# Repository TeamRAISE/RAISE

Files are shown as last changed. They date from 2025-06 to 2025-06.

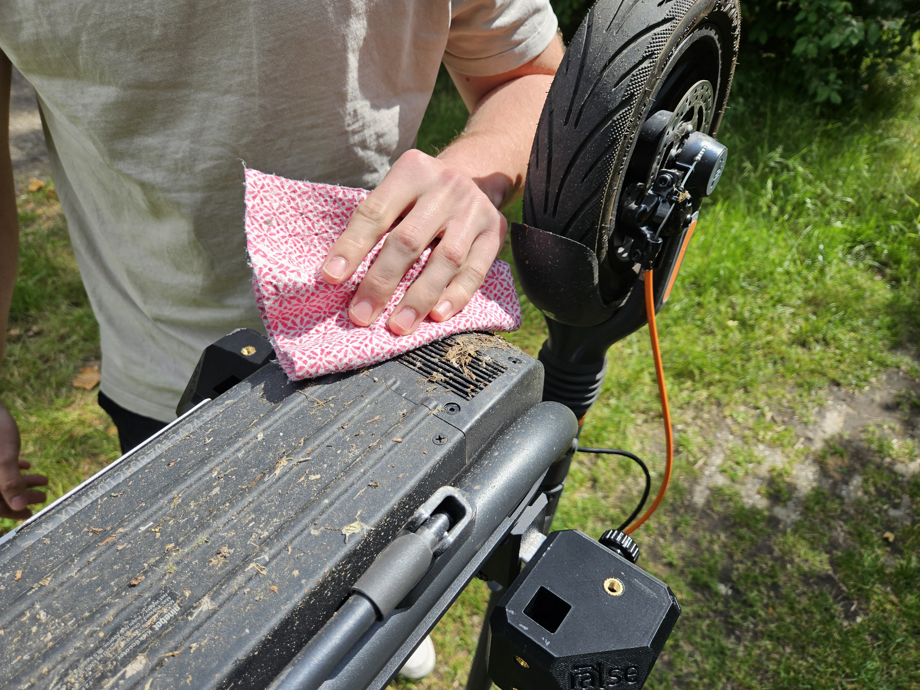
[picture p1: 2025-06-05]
Pictures/Wartungsgestell_Bild_03.jpg

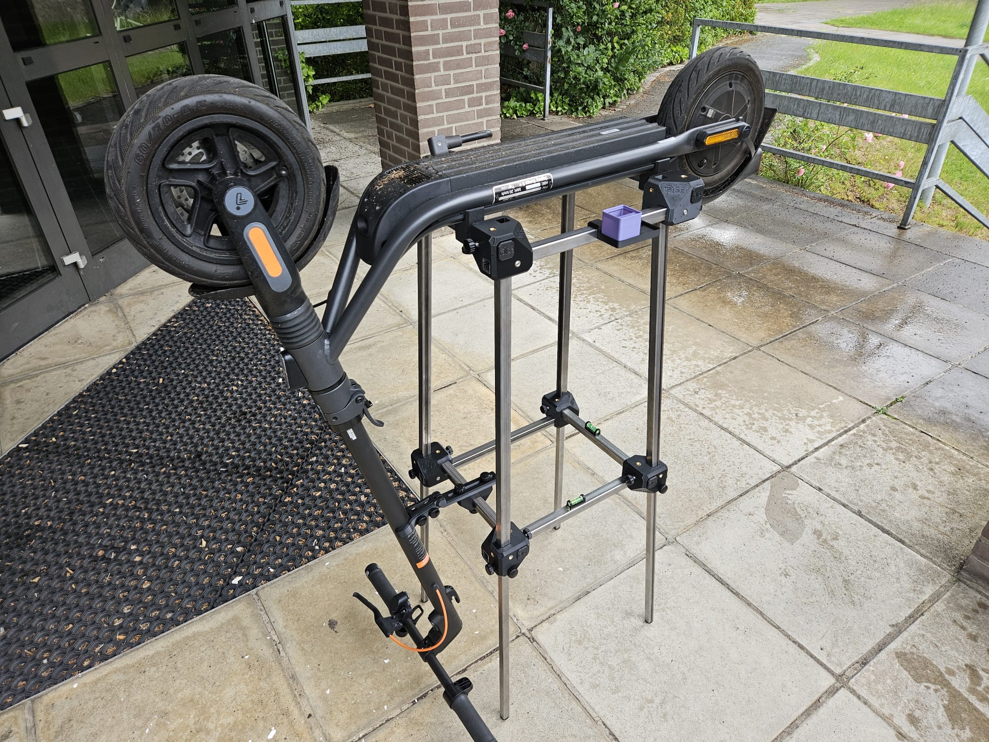
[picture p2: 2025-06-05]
Pictures/Wartungsgestell_Bild_05.jpeg

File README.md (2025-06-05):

# RAISE
Repair and Inspection Stand for E-Scooter

RAISE ist ein Wartungsgestell für E-Scooter. Wenn man einen E-Scooter besitzt, ist man für die Wartung,
Instandhaltung und das Reinigen des Rollers verantwortlich. Die Form des Rollers ist für eine Wartung
und Reinigung an der Unterseite ungünstig. Aufgrund der hohen Lenksäule und dem Hinterradspritzschutz
ist ein einfaches Ablegen auf einer herkömmlichen Tischplatte nicht möglich. Mit diesem an die Abmaße
eines E-Scooters angepassten Wartungsgestell ist es möglich, die Unterseite des Rollers auf eine angenehme
Arbeitshöhe zu bringen. Die zum Nachbau des Gestells benötigten Teile sind hier auf GitHub hinterlegt.
Es lässt sich mit einem 3D-Drucker und einfachen Mitteln aus dem Baumarkt nachbauen.

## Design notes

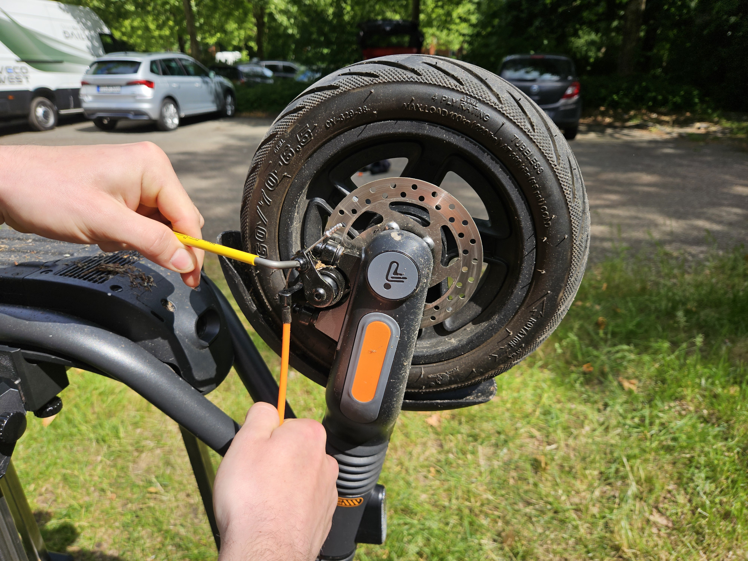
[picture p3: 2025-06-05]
Pictures/Wartungsgestell_Bild_02.jpg

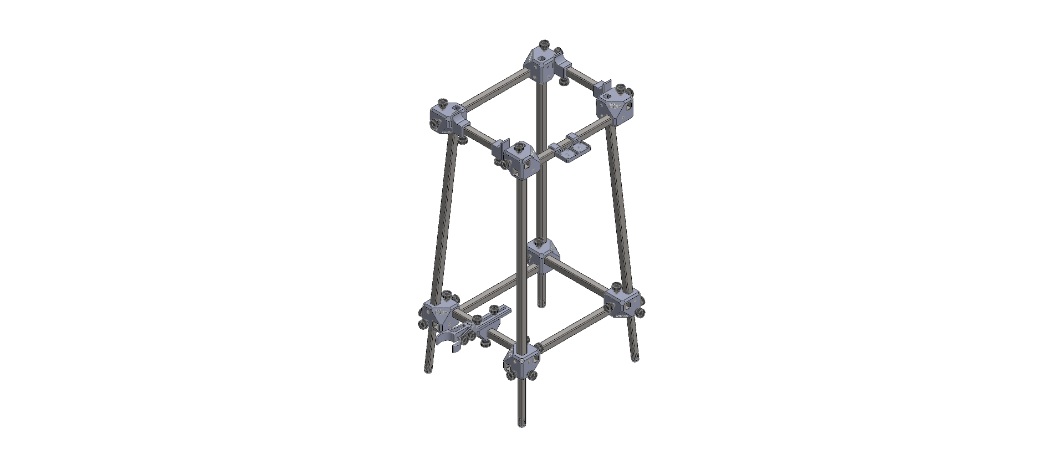
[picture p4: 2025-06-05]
Pictures/Wartungsgestell_Bild_01.PNG

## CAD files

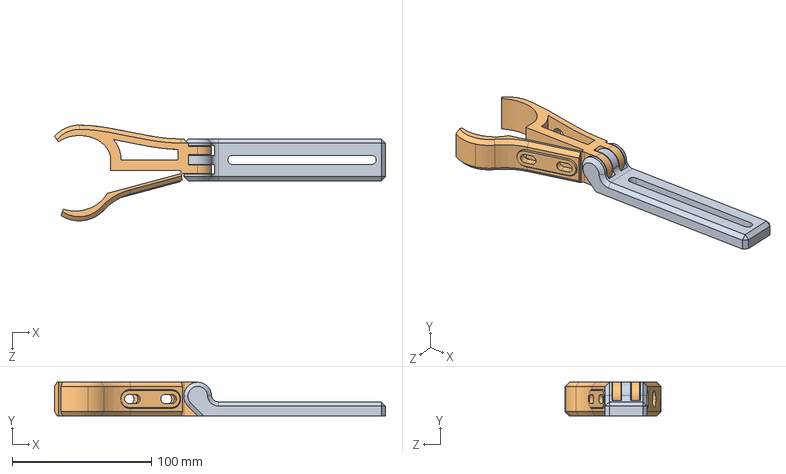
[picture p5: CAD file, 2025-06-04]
CAD/Säulenhalterung_Klemme_o.STEP
237.9 x 24.1 x 68.8 mm

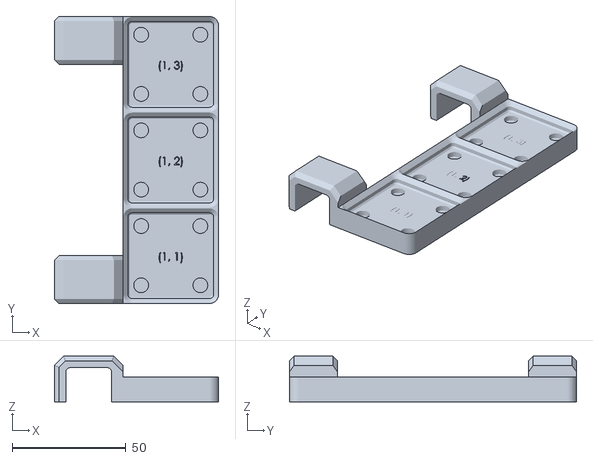
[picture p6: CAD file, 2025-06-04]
STL/Gridfinity/Baseplate_1-3.STL
72.1 x 126.0 x 20.0

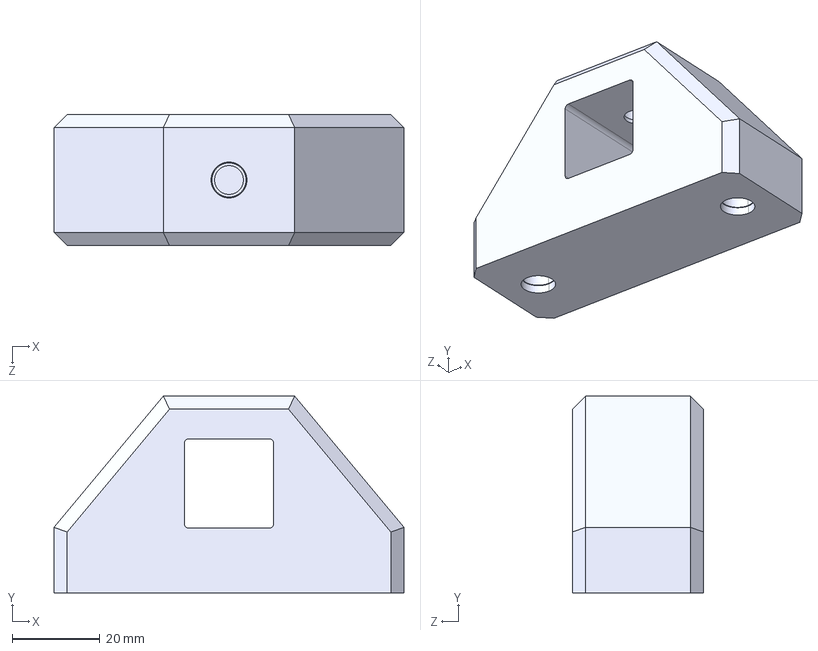
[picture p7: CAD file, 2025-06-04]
CAD/Säulenhalterung_Brücke_o.STEP
80.0 x 45.0 x 30.0 mm

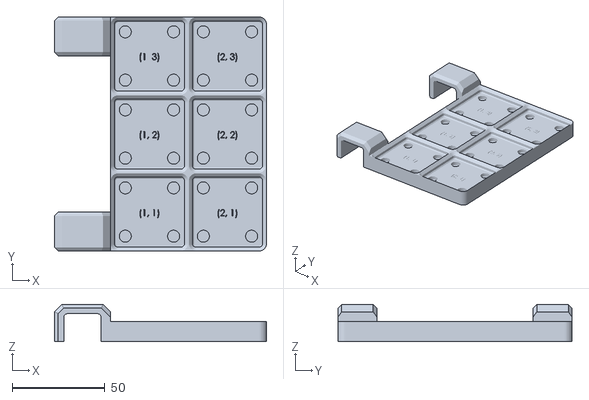
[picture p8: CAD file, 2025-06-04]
STL/Gridfinity/Baseplate_2-3.STL
114.1 x 126.0 x 20.0

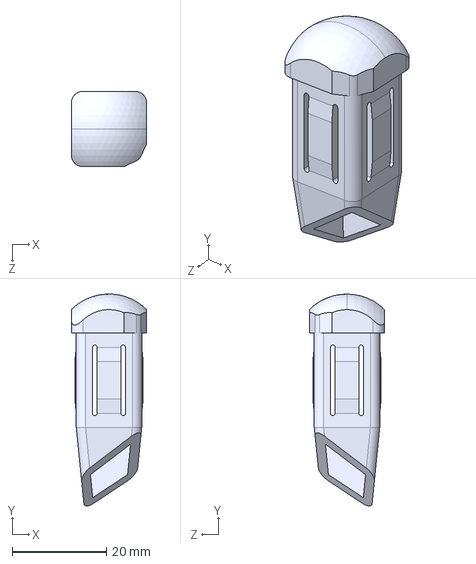
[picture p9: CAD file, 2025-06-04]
CAD/Endkappe_Fuß_x4.STEP
16.0 x 45.0 x 16.0 mm

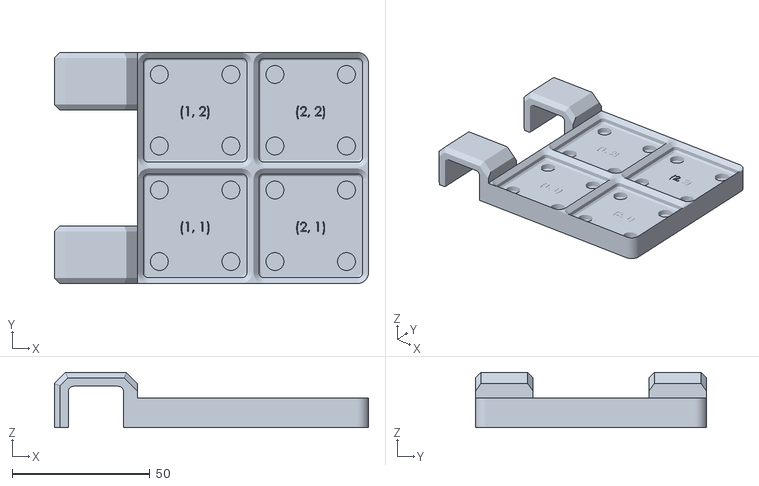
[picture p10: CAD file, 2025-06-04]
STL/Gridfinity/Baseplate_2-2.STL
114.1 x 84.0 x 20.0

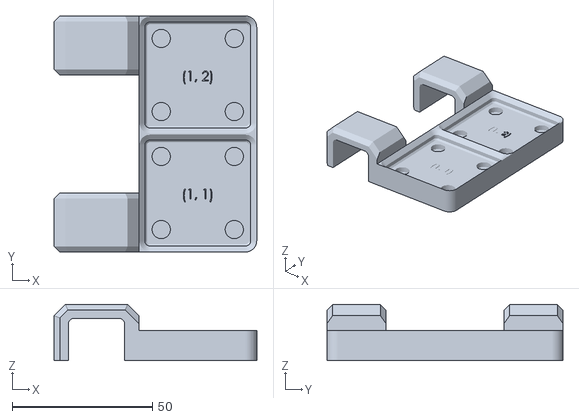
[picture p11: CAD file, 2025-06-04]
STL/Gridfinity/Baseplate_1-2.STL
72.1 x 84.0 x 20.0

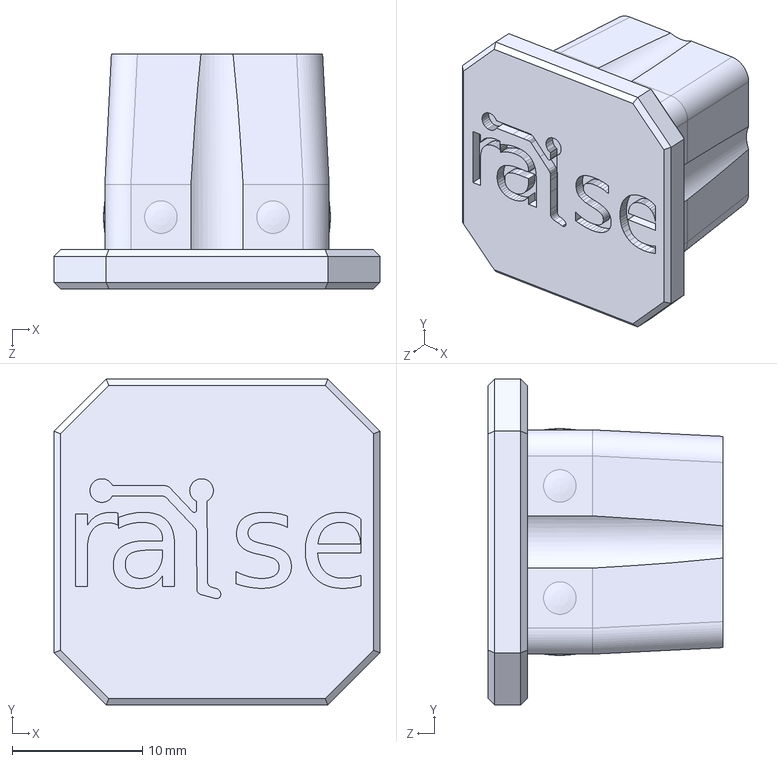
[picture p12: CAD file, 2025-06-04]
CAD/Endkappe_Logo_x16.STEP
25.0 x 25.0 x 18.0 mm

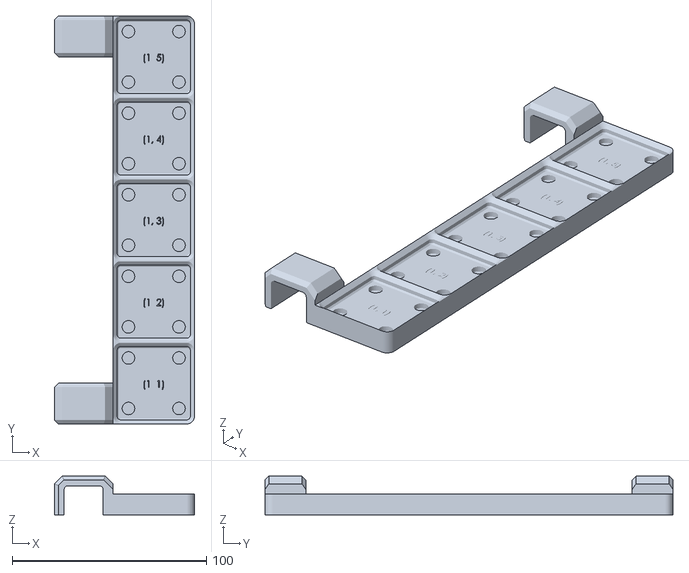
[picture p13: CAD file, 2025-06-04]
STL/Gridfinity/Baseplate_1-5.STL
72.1 x 210.0 x 20.0

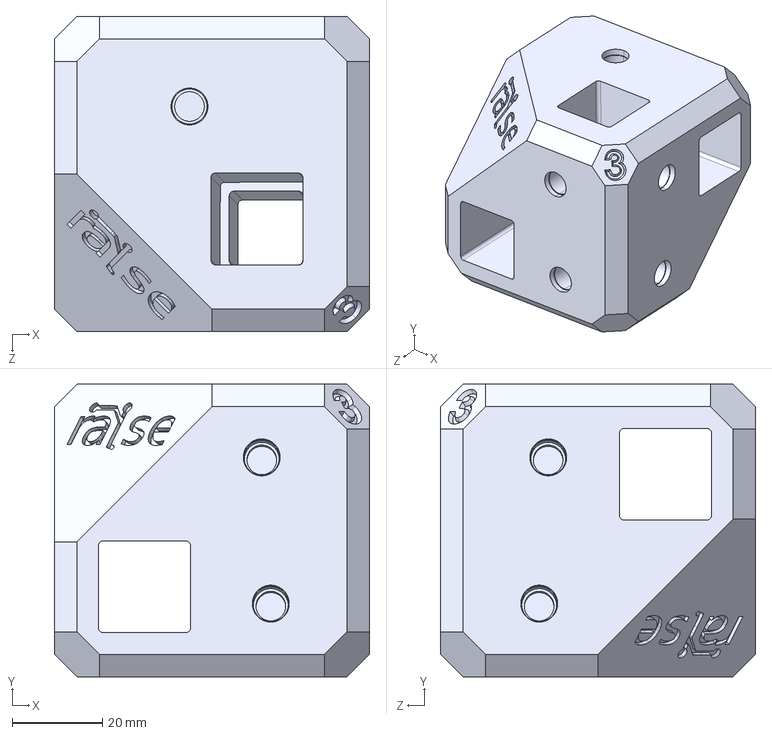
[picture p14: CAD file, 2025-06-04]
CAD/Eckwürfel_links_x4.STEP
70.0 x 65.0 x 70.0 mm

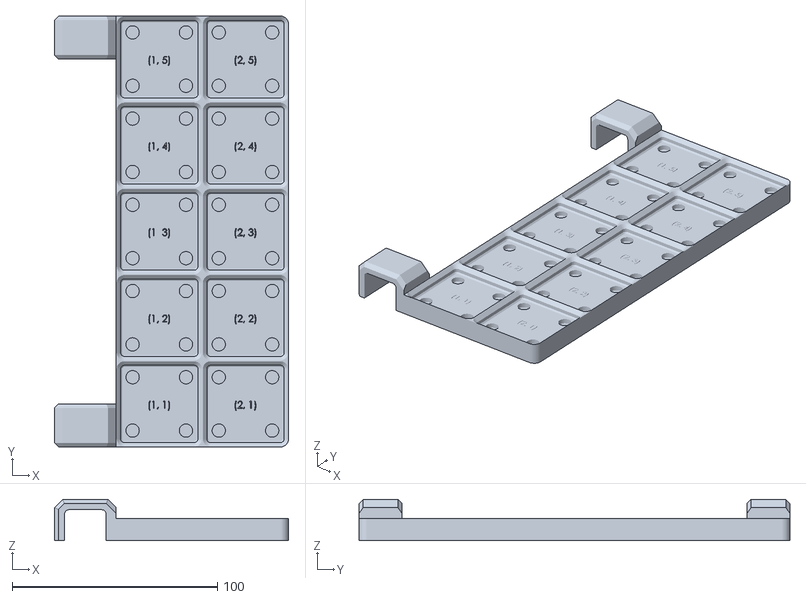
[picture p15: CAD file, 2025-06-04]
STL/Gridfinity/Baseplate_2-5.STL
114.1 x 210.0 x 20.0

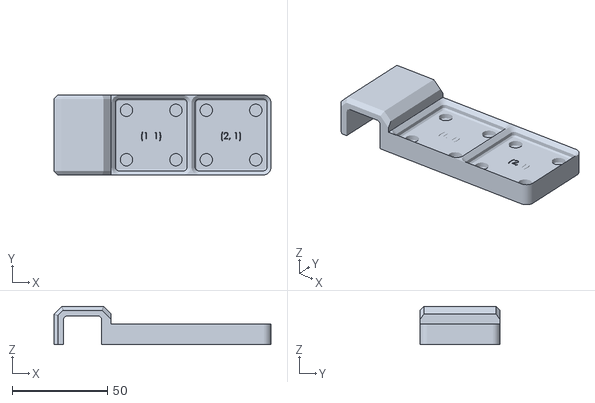
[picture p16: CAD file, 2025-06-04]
STL/Gridfinity/Baseplate_2-1.STL
114.1 x 42.0 x 20.0

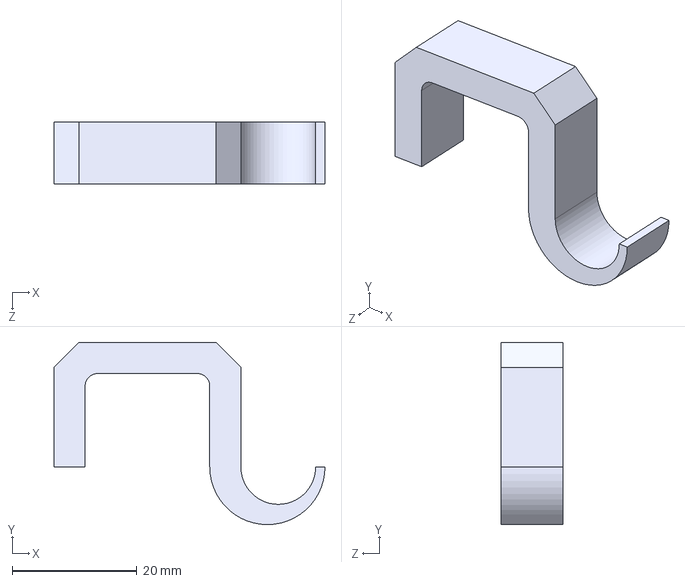
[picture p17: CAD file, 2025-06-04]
CAD/Haken_o.STEP
43.5 x 29.2 x 10.0 mm

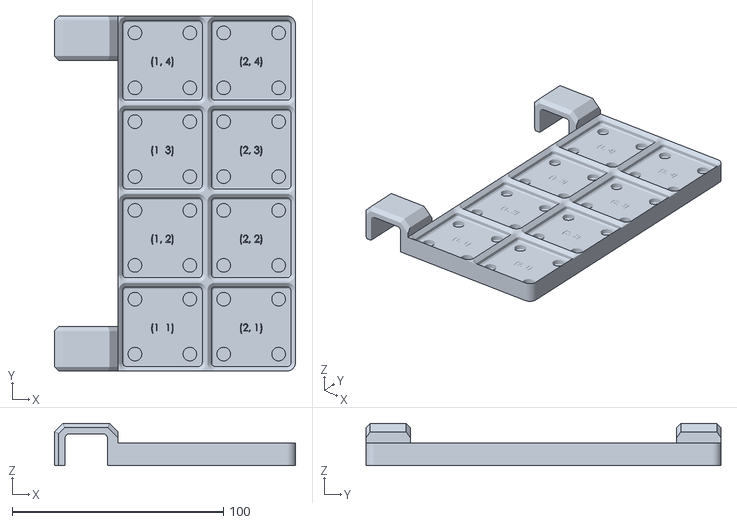
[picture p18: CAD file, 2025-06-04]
STL/Gridfinity/Baseplate_2-4.STL
114.1 x 168.0 x 20.0

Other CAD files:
CAD/Säulenhalterung_Brücke_01.STEP
CAD/Eckwürfel_rechts_x4.STEP
CAD/Endkappe_Fuß_01.STEP
STL/Gridfinity/Baseplate_1-4.STL
CAD/Scooter_Klemme_x4.STEP
CAD/Säulenhalterung_Klemme_01.STEP
STL/Eckwürfel_links_x4.STL
STL/Eckwürfel_rechts_x4.STL
STL/Endkappe_Fuß_x4.STL
STL/Endkappe_Logo_x16.STL
STL/Haken_o.STL
STL/Scooter_Klemme_x4.STL
STL/Säulenhalterung_Brücke_o.STL
STL/Säulenhalterung_Klemme_o.STL

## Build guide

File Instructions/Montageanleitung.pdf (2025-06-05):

Montageanleitung

RAISE die Scooter-Inspektionshalterung

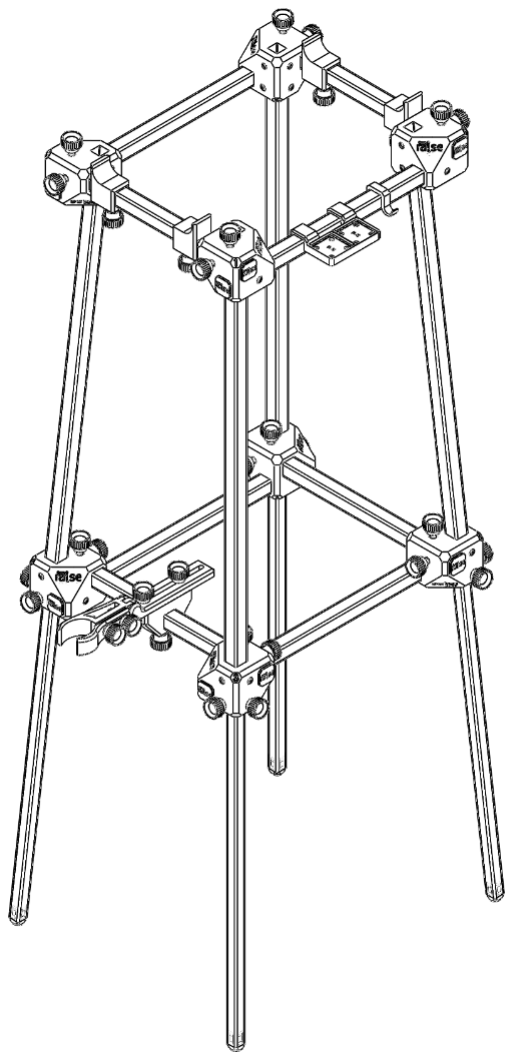
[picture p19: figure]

II

Vorwort

Das Thema Wartung und Reinigung ist ein Thema, mit dem sich ein ordentlicher und verantwortungsvoller Benutzer von E-Scootern auseinandersetzen muss.

Für diese Applikationen wurde von Studierenden in Gruppenarbeit eine Vereinfachung dieser Tätigkeiten geschaffen, welche im Folgenden für Sie als Leser, kostenlos und einfach erklärt werden.

Die zum Nachbauen benötigten Maße und 3D-Druck-Daten, welche für die auf dem Markt verbreiteten Modelle geeignet sind, werden bereitgestellt und die Zukaufteile gelistet. Die Arbeitsschritte sind in
chronologischer | Reihenfolge | erklärt | und
entsprechend zum Nachbau veranschaulicht.

Falls Unklarheiten oder Fragen aufkommen sollten, können Sie diese im Kommentarbereich dieser Anleitung stellen.

III

Inhalt

Vorwort | II

1. Vorbereitungen
1.1 Additive Fertigung der Modelle

Die STL-Dateien können nach dem Herunterladen in jedem Slicer-Programm geöffnet und zum Drucken vorbereitet werden. Benötigt werden etwa 1,65kg Filament. Die wichtigsten Einstellungen hier einmal zusammengefasst:
1. Material:(PETG, ABS, oder Vergleichbares)
2. Min. 40% Infill
3. Kubisches Infillmuster
4. Min. 5 Wandlinien
Die Würfel sind so ausgelegt, dass sie ohne Support gedruckt werden können. Dafür müssen die Würfel auf einer der Ecken mit dem Logo liegen, siehe Abbildung1. Die Endkappen können mit den gleichen Einstellungen und wie in Abbildung 2 gezeigt gedruckt werden. Eventuell ist es notwendig zur besseren Druckbetthaftung der Füße „Brims“ zu verwenden. Die optionale Säulenhalterung mit Brücke und Klammer können ebenfalls beide ohne Support gedruckt werden wie in Abbildung 3. Die Klemmen für den Scooter können ebenfalls ohne Support gedruckt werden, nur die Gridfinity Platte benötigt Support (Abbildung 4).

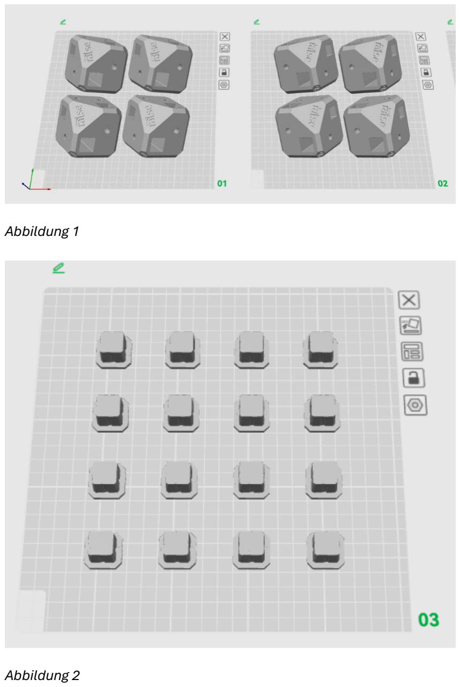
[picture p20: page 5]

Abbildung 1

Abbildung 2

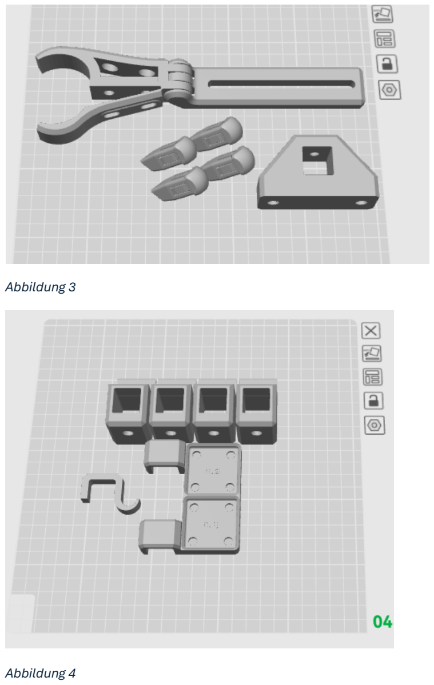
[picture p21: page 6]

Abbildung 3

Abbildung 4

1.2 Zuschnitt der Vierkantrohre

Die Maße des Gestells sind für die meisten gängigen E-Scooter ausgelegt. Für eine optimale Kompatibilität sollte der Scooter folgende Merkmale aufweisen:

- max. Trittbrett-Breite: 175mm
- min. ebene Trittbrett-Länge 390mm
- max. Höhe (Trittbrett bis Lenker): 1100mm Zu verwenden sind handelsübliche Vierkantrohre in □16mm und □20mm. Diese müssen gut ineinander
gleiten können und folgenden Maßen entsprechen: 330 x □²⁰ | 500 x

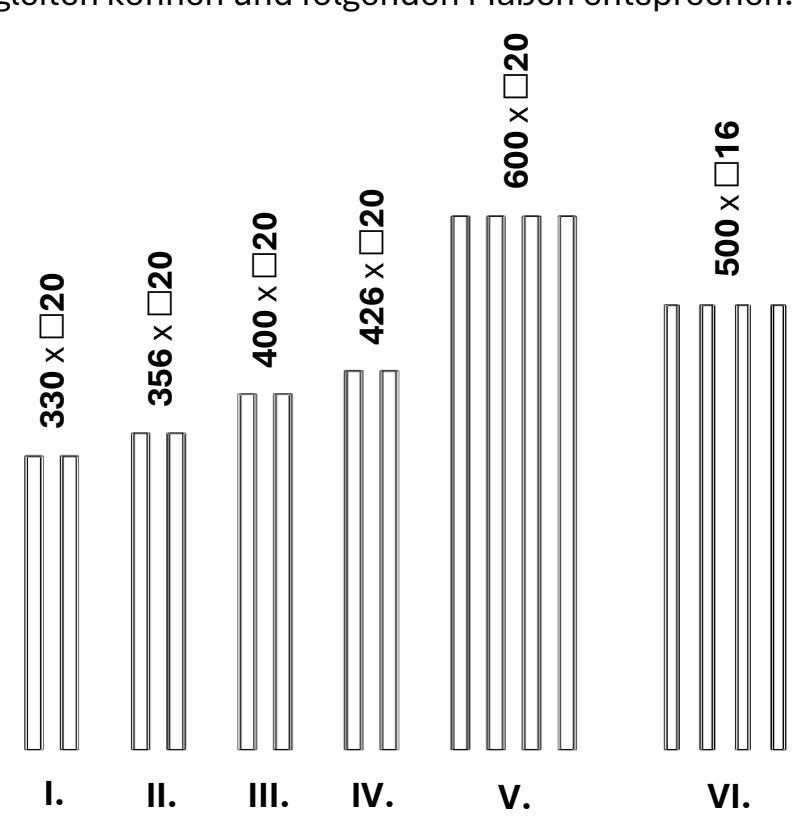
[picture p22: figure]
III.

Bei Abweichungen der Scooter-Merkmale müssen folgende Formeln benutzt werden, um angepasste Rohrmaße zu erhalten:
Wenn Breite > 175mm:
- Rohrlänge I. = Trittbrett-Breite + 160mm
- Rohrlänge II. = Rohrlänge I + 26mm Wenn Trittbrett-Länge < 390mm:
- Rohrlänge III. = Trittbrett-Länge + 10mm
- Rohrlänge IV. = Rohrlänge III. + 26mm Wenn Höhe > 1100mm:
- Rohrlänge VI. = Höhe – 590mm

2. Übersicht benötigter Bauteile
Nr. | Bauteil | Anz. | Bild
1. | Eckwürfel links | 4x
2. | Eckwürfel rechts | 4x
3. | Endkappe Fuß | 4x
4. | Endkappe Logo | 16x
5. | Fixier-Klemmen | 4x
6. Einschmelzmutter | M6 | 73x
7. Gewindestift | M6x10 | 32x
8. Rändelschraube | M6x16 | 28x

Hinweis: Optionales Zubehör bedarf zusätzlichen Materials, siehe S. 24f.

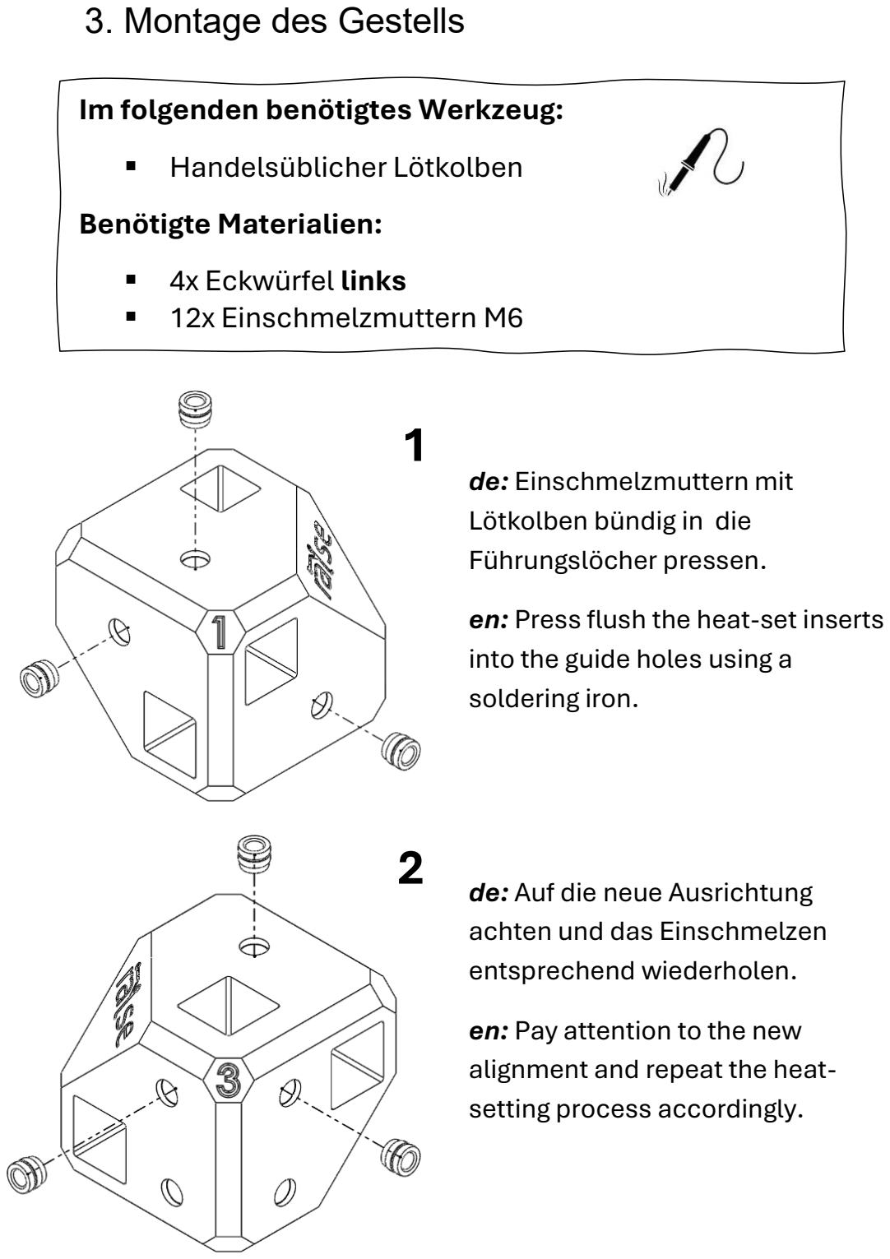
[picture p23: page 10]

3. Montage des Gestells

de: Einschmelzmuttern mit
Lötkolben bündig in die
Führungslöcher pressen.

en: Press flush the heat-set inserts into the guide holes using a soldering iron.

1

### 2 de: Auf die neue Ausrichtung

achten und das Einschmelzen entsprechend wiederholen.

en: Pay attention to the new alignment and repeat the heat-setting process accordingly.

Im folgenden benötigtes Werkzeug:
- Handelsüblicher Lötkolben Benötigte Materialien:
- 4x Eckwürfel links
- 12x Einschmelzmuttern M6

3
de: Die Schritte 1 & 2 für alle vier Eckwürfel links wiederholen en: Repeat steps 1 and 2 for all four left corner cubes.

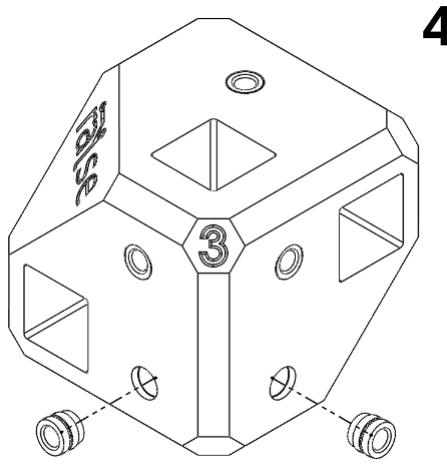
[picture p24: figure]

4

de: Dieses Vorgehen nur für zwei Eckwürfel links durchführen, nachfolgend „Eckwürfel links Typ 2“ genannt.
en: Carry out this procedure only for two corner cubes on the left, hereafter referred to as “Left Corner Cubes Type 2”.

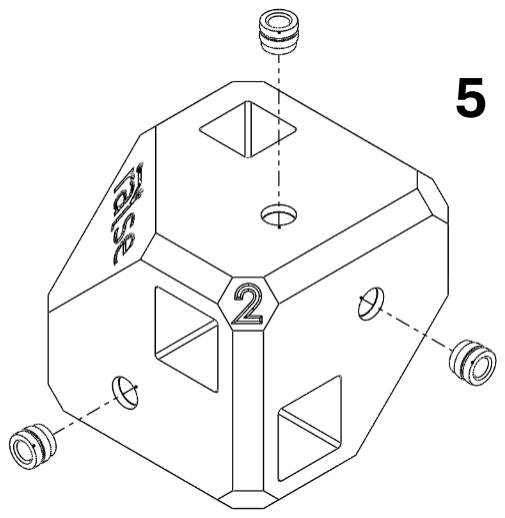
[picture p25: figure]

### 5 de: Einschmelzmuttern mit

Lötkolben bündig in die
Führungslöcher pressen.

en: Press flush the heat-set inserts into the guide holes using a soldering iron.

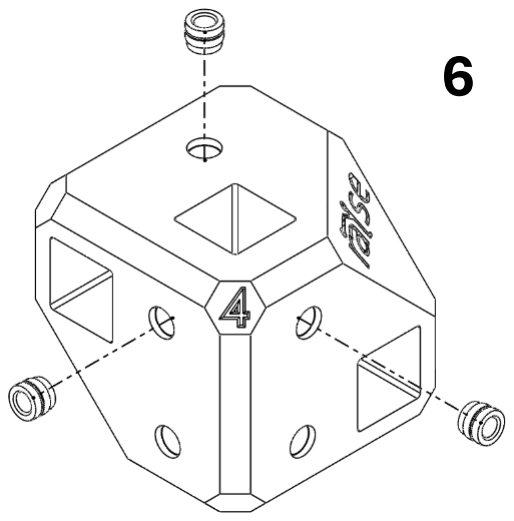
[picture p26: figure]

de: Auf die neue Ausrichtung achten und das Einschmelzen entsprechend wiederholen.

en: Pay attention to the new alignment and repeat the heat-setting process accordingly.

7
de: Die Schritte 5 & 6 für alle vier Eckwürfel rechts wiederholen en: Repeat steps 5 and 6 for all four right corner cubes.

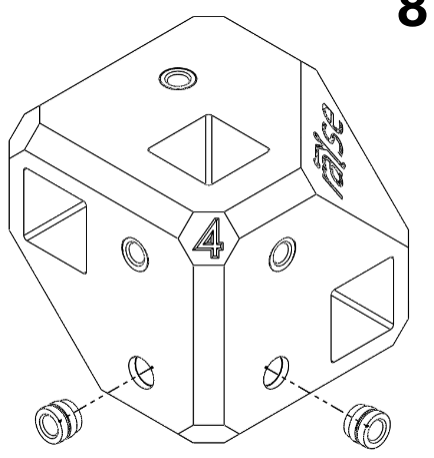
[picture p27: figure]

8
de: Dieses Vorgehen nur für zwei Eckwürfel rechts durchführen. nachfolgend „Eckwürfel rechts Typ 2“ genannt.

en: Carry out this procedure only for two corner cubes on the right, hereafter referred to as “Right Corner Cubes Type 2”.

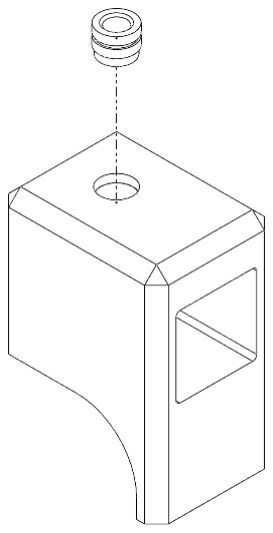
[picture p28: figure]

9

de: Alle vier Klemmen mit
Einschmelzmuttern bestücken.

en: Equip all four clamps with heat-set inserts.

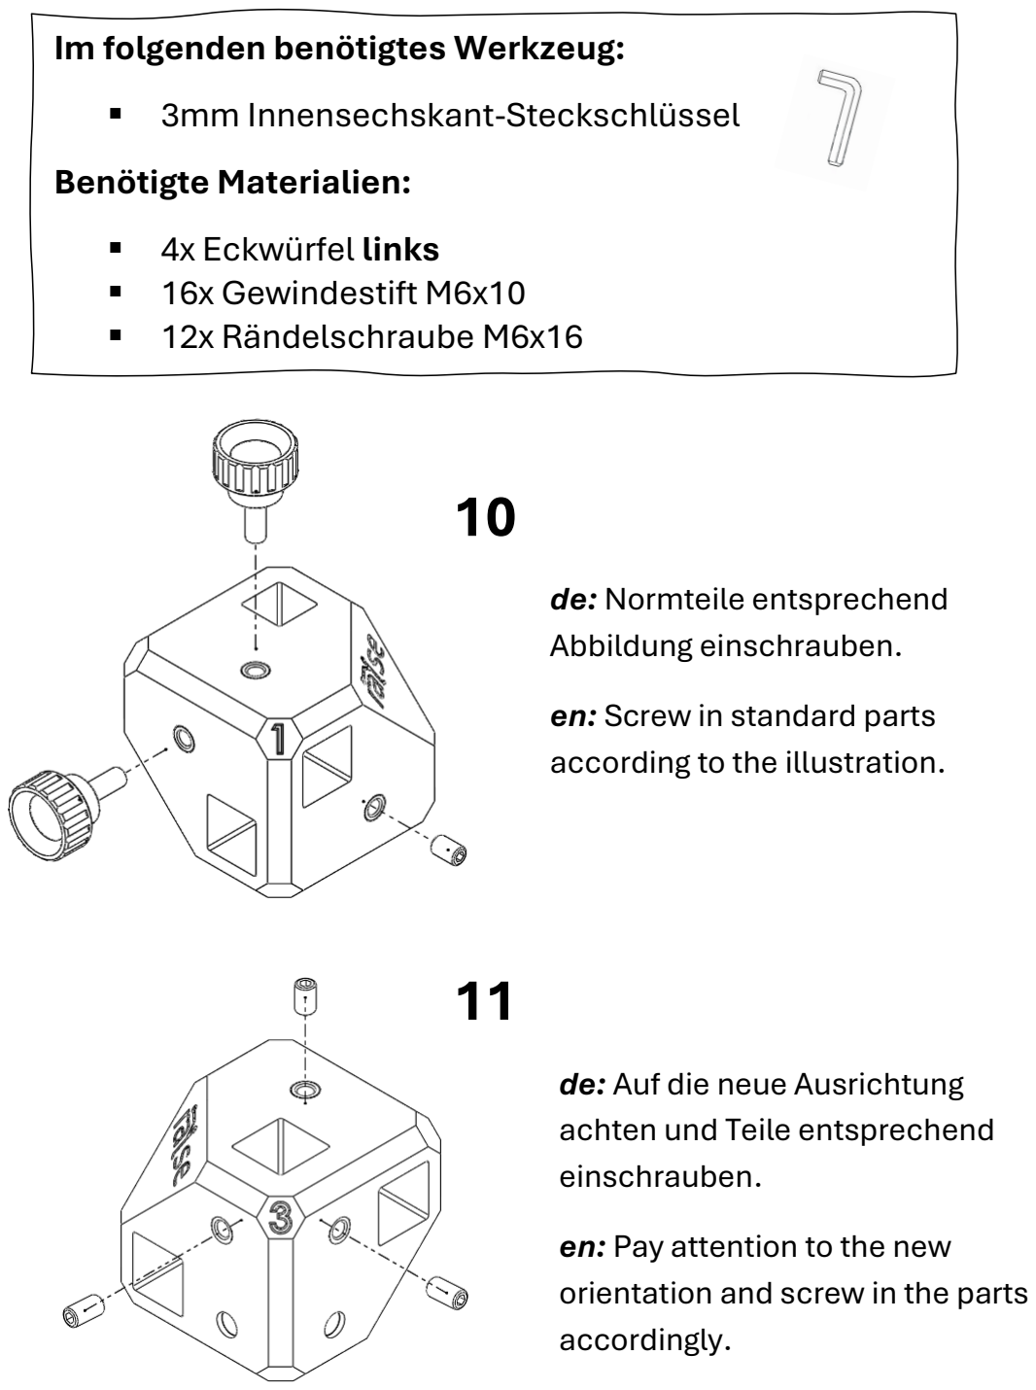
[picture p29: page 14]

10

de: Normteile entsprechend Abbildung einschrauben.
en: Screw in standard parts according to the illustration.

11

de: Auf die neue Ausrichtung achten und Teile entsprechend einschrauben.
en: Pay attention to the new orientation and screw in the parts accordingly.

Im folgenden benötigtes Werkzeug:
- 3mm Innensechskant-Steckschlüssel Benötigte Materialien:
- 4x Eckwürfel links
- 16x Gewindestift M6x10
- 12x Rändelschraube M6x16

12

de: Die Schritte 10 & 11 jeweils an zwei Eckwürfel links durchführen, diese gelten nun als fertig bestückt.
en: Perform steps 10 & 11 on two left corner cubes, these are now considered fully assembled.

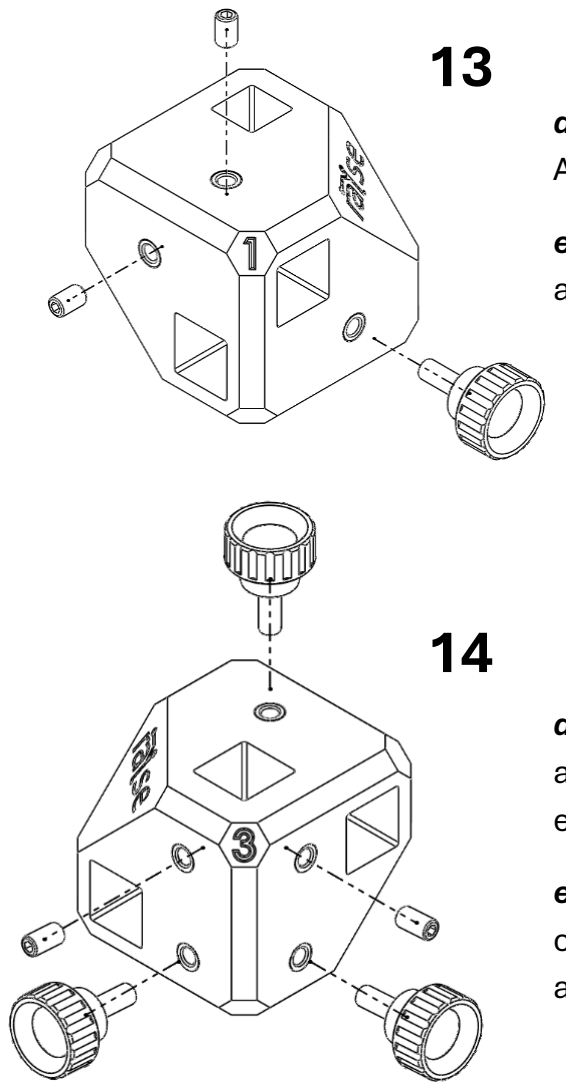
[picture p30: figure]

de: Normteile entsprechend Abbildung einschrauben.

en: Screw in standard parts according to the illustration.

de: Auf die neue Ausrichtung achten und Teile entsprechend einschrauben.

en: Pay attention to the new orientation and screw in the parts accordingly.

de: Die Schritte 10 & 11 jeweils an den zwei übrigen Eckwürfel links Typ 2 durchführen.
en: Perform steps 10 & 11 on the two remaining left corner cubes Type 2.

15

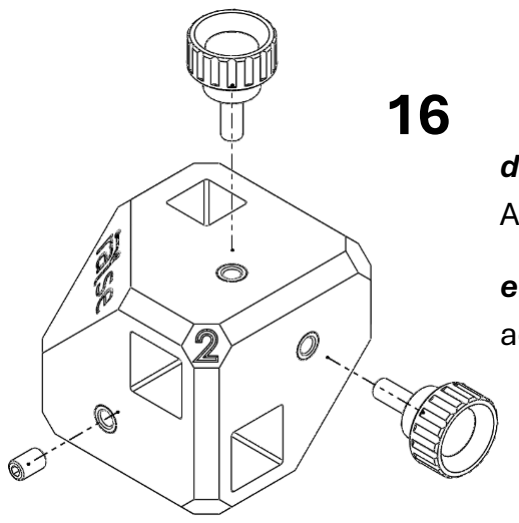
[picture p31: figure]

de: Normteile entsprechend Abbildung einschrauben.

en: Screw in standard parts according to the illustration.

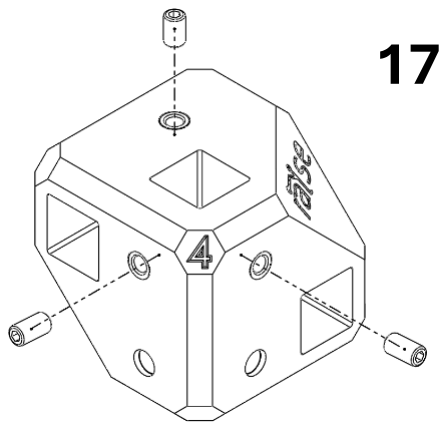
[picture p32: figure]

de: Auf die neue Ausrichtung achten und Teile entsprechend einschrauben.

en: Pay attention to the new orientation and screw in the parts accordingly.

18

de: Die Schritte 16 & 17 jeweils an zwei Eckwürfel rechts durchführen, diese gelten nun als fertig bestückt.
en: Perform steps 16 & 17 on two right corner cubes, these are now considered fully assembled.

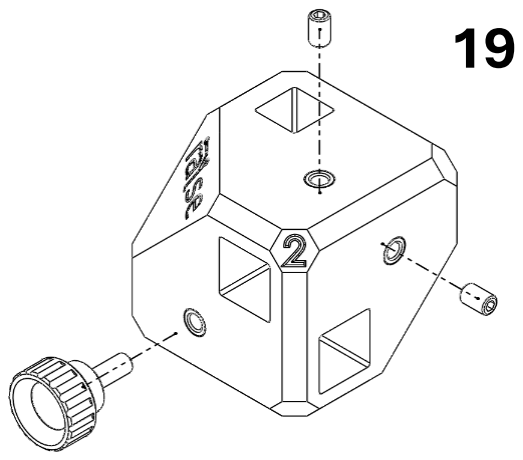
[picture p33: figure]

de: Normteile entsprechend Abbildung einschrauben.

en: Screw in standard parts according to the illustration.

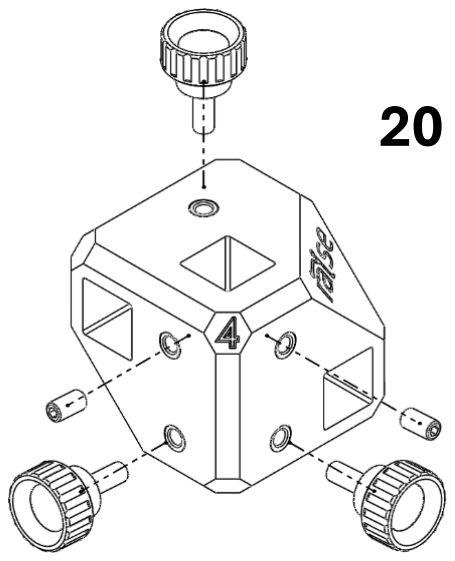
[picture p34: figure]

de: Auf die neue Ausrichtung achten und Teile entsprechend einschrauben.
en: Pay attention to the new orientation and screw in the parts accordingly.

de: Die Schritte 19 & 20 jeweils an den zwei übrigen Eckwürfel rechts Typ 2 durchführen.
en: Perform steps 19 & 20 on the two remaining right corner cubes Type 2.

21

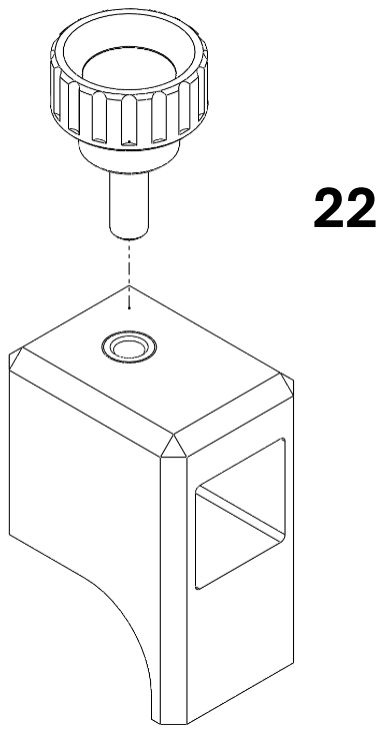
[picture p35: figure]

de: Alle vier Klemmen mit den Rändelschrauben ausstatten

en: Equip all four clamps with thumb screws.

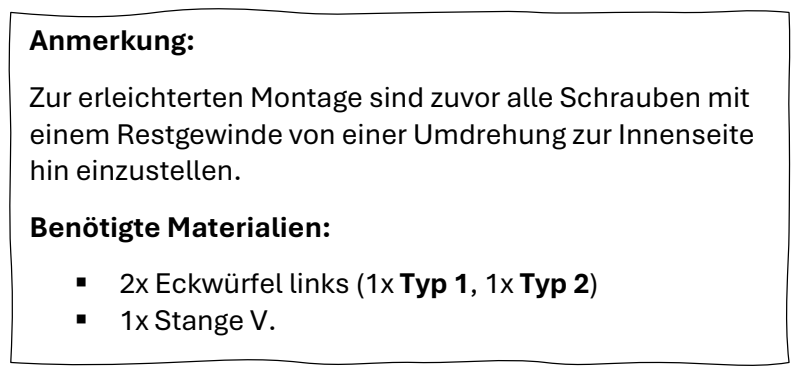
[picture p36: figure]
Anmerkung:; hin einzustellen.; Benötigte Materialien:; ▪ 1x Stange V.

Zur erleichterten Montage sind zuvor alle Schrauben mit einem Restgewinde von einer Umdrehung zur Innenseite

- 2x Eckwürfel links (1x Typ 1, 1x Typ 2)

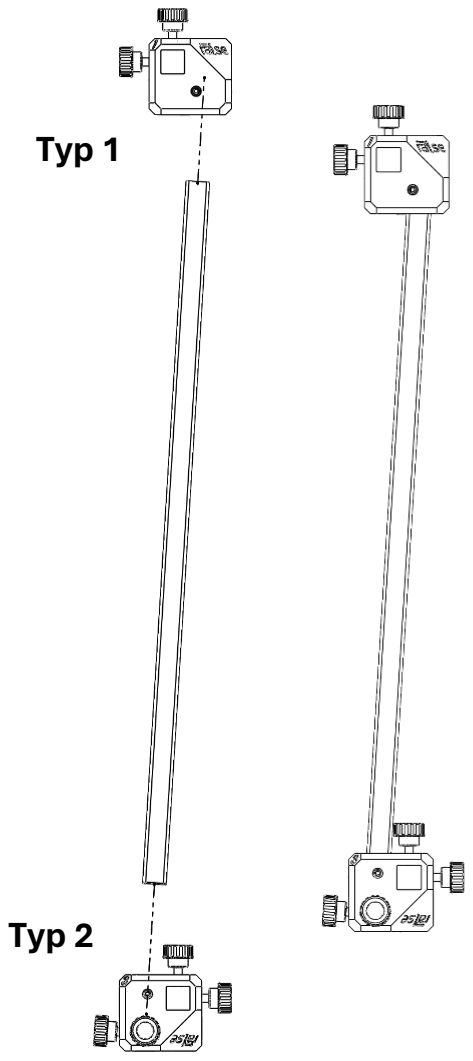
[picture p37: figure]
Typ 2; Typ 1

23

de: Unter leichtem Druck die Stangenenden in die Würfel stecken

en: Insert the rod ends into the cubes with light pressure.

- 2x Eckwürfel rechts (1x Typ 1, 1x Typ 2)

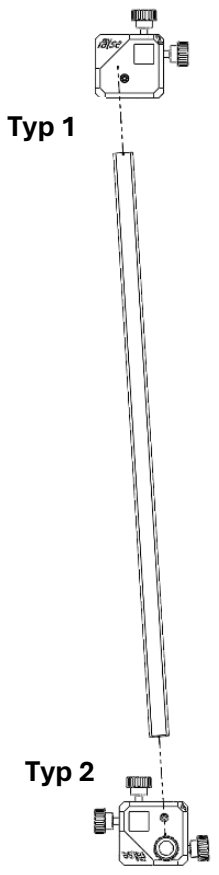
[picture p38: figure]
Typ 2; Typ 1

de: Unter leichtem Druck die Stangenenden in die Würfel stecken
en: Insert the rod ends into the cubes with light pressure.

24

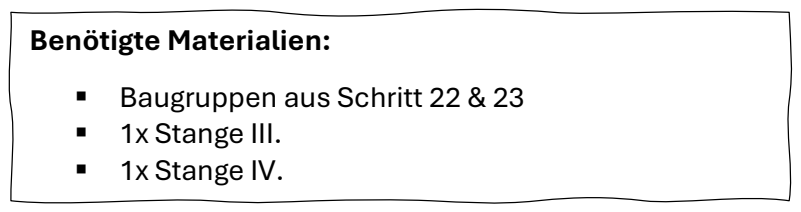
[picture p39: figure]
Benötigte Materialien:; ▪ Baugruppen aus Schritt 22 & 23 ▪ 1x Stange III. ▪ 1x Stange IV.

25

de: Unter leichtem Druck die Stangenenden gleichmäßig in die Würfel stecken

en: Insert the rod ends evenly into the cubes with light
pressure.

de: Die zwei Endkappen in die zwei Stangen pressen

en: Press the two end caps into the two rods.

26

27

de: Die zwei Stangen in das Gestell führen und arretieren en: Insert the two rods into the frame and lock them in place.

28

de: Die Schritte 23 – 27 insgesamt 2x durchführen.

en: Perform steps 23–27 a total of 2 times.

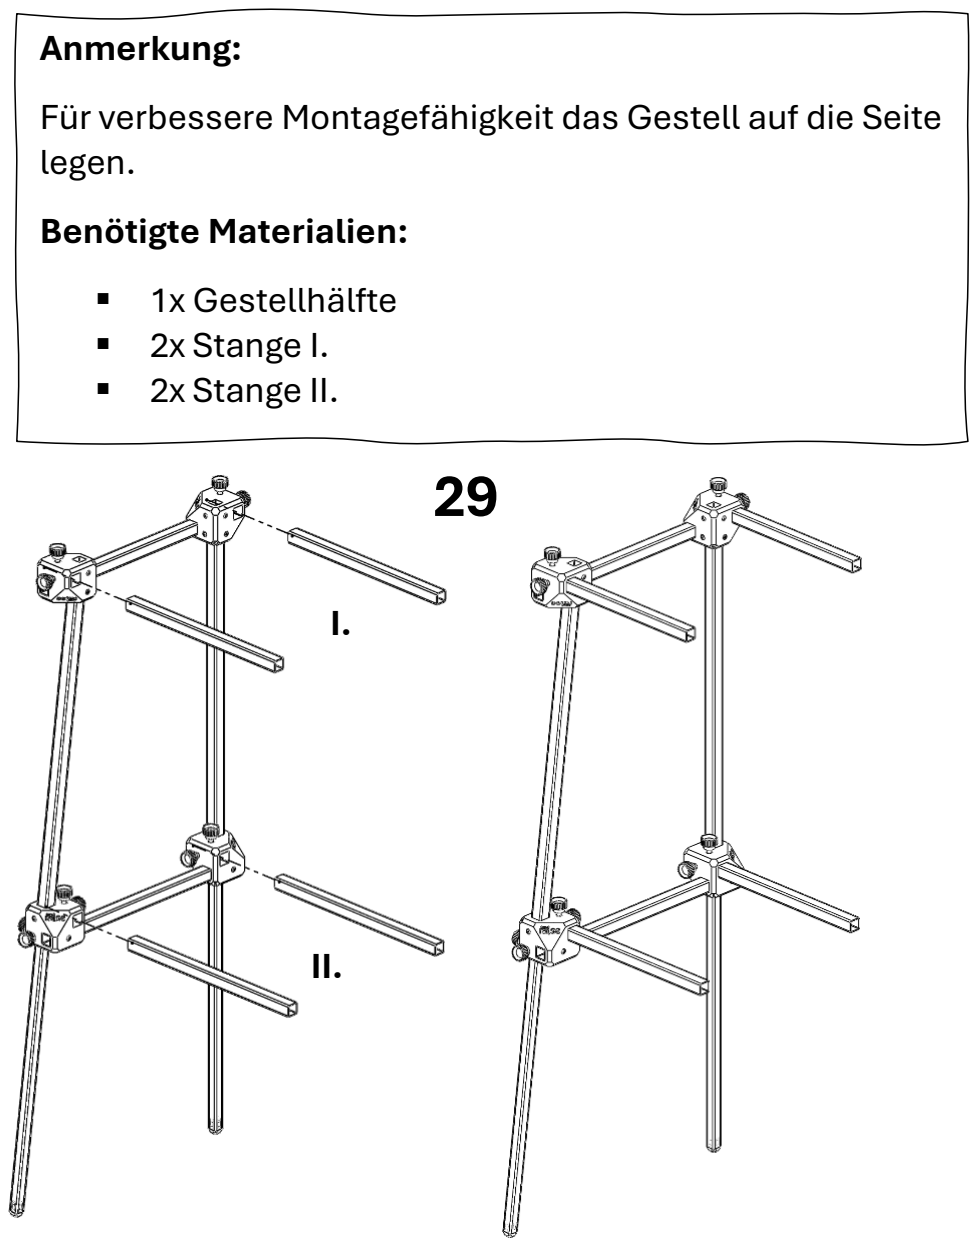
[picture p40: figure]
Anmerkung:; legen.; Benötigte Materialien:; ▪ 1x Gestellhälfte ▪ 2x Stange I. ▪ 2x Stange II.

Für verbessere Montagefähigkeit das Gestell auf die Seite

30

de: Die Klemmen
positionieren und arretieren. (ggf. Schritt 33.2
berücksichtigen)

en: Position and lock the
clamps in place (consider step 33.2 if applicable)

31

de: Unter leichtem Druck die Stangenenden gleichmäßig in die Würfel stecken

en: Insert the rod ends evenly into the cubes with light
pressure.

32

de: Alle 16x Endkappen in die Stangenendungen drücken.

en: Press all 16 end caps into the rod ends.

33

de: Die Gridfinity Halterung und den Haken auf das Gestell stecken, sowie die magnetischen Wasserwaagen zwecks Nivellierung nach Belieben befestigen.

en: Attach the Gridfinity mount and the hook to the frame and fasten the magnetic spirit levels as desired for leveling purposes.

Lenksäulenhalter

Die Geometrie des Gestells bietet allein durch die Auflagefläche des Scooters insgesamt einen sehr stabilen Stand. Sollte noch zusätzlicher Halt notwendig sein, so können folgende Schritte dazu

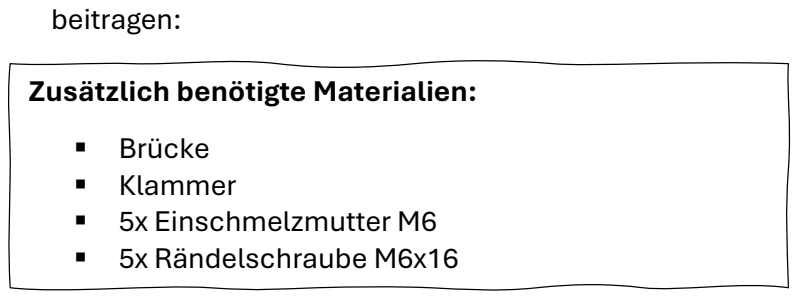
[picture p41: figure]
beitragen:; Zusätzlich benötigte Materialien:; ▪ Brücke ▪ Klammer ▪ 5x Einschmelzmutter M6 ▪ 5x Rändelschraube M6x16
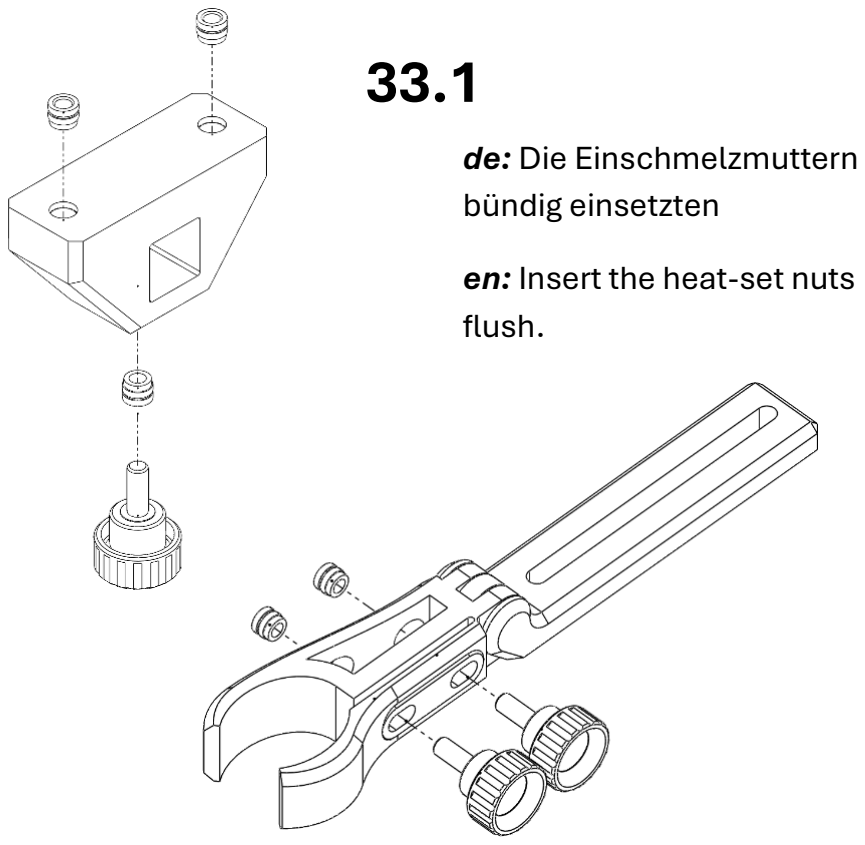
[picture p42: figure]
de: Die Einschmelzmuttern bündig einsetzten; en: Insert the heat-set nuts flush.

33.2

de: Die Montage der Brücke während Schritt 30 ergänzen und die Rändelschrauben entsprechend einschrauben.

en: Include the mounting of the bridge during step 30 and screw in the thumb screws accordingly.

## 4. Bedienung

- Teleskopstangen auf die passende Höhe ausfahren
- Scooter auflegen, Klemmen anschieben und festziehen
- Klammer um die Lenkstange legen und festziehen
➔ An die Arbeit!

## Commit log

2025-06-04 Update and rename Endkappe_Fuß_01.STEP to Endkappe_Fuß_x4.STEP
    [Endkappe_Fuß_x4.STEP]
2025-06-04 Update and rename Endkappe_Logo.STEP to Endkappe_Logo_x16.STEP
    [Endkappe_Logo_x16.STEP]
2025-06-04 Update and rename Haken.STEP to Haken_o.STEP
    [Haken_o.STEP]
2025-06-04 Update and rename Scooter_Klemme_01.STEP to Scooter_Klemme_x4.STEP
    [Scooter_Klemme_x4.STEP]
2025-06-04 Update and rename Säulenhalterung_Brücke_01.STEP to Säulenhalterung_Brücke_o.STEP
    [Säulenhalterung_Brücke_o.STEP]
2025-06-04 Update and rename Säulenhalterung_Klemme_01.STEP to Säulenhalterung_Klemme_o.STEP
    [Säulenhalterung_Klemme_o.STEP]
